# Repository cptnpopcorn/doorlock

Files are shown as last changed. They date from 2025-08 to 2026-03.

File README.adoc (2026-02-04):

# Introduction

This repository is based on code from elmu's electronic doorlock project (see `archive` folder). This project was a real-use, working application to manage access to a house using encrypted DESFire cards from NXP.

What it does is changing the target to a more modular application, where the card verification and door control is separated. The central control mechanism that links those two components can be anything that communicates via MQTT.

A PC-plus-FT232H dongle based programmer application is provided, to manually write user IDs on cards.

## Project Structure

The top folders

common:: shared, generic C++ libraries and applications (CMake-based), and *global configuration*
common-esp32:: shared, esp32-specific libaries ("components")
esp32-cardreader:: esp32 application reading NFC cards and pubslishing extracted user IDs via MQTT

### Common

config:: the one central place to define your secret keys used to encrypt cards and MQTT communication
cardwriter:: desktop CLI application to verify and write cards via a FT232H USB/SPI dongle
external:: some CMake magic to find and integrate your locally installed FTDI dongle libraries
libdesfire:: re-factored NXP PN532 library from elmu (now with runtime hardware abstraction)
libdesfire_tests:: unit tests for rewritten PN532 message parsing abstraction
pn532-ft232h:: PN532 interface implementation via FT232H, working for SPI. Tried I2C but since the FT232H does not support the clock stretching applied by the PN532, it seems to be a dead end..
test-ft232h:: some basic system test to verify / diagnose basic FT232H + PN532 operations

## Card reader application (ESP32)

### Configuration (ESP-IDF menuconfig)

You can set up your specific MQTT subject, encryption etc. under the `MQTT` component settings. For the PN532 specific GPIO pins, they can be changed in the `PN532 GPIO Pins` section.

## Using PN532 from a PC via a FT232H USB Dongle

### Required libraries

* You need to get the ft2xx user space driver (dll or static) as provided by FTDI (https://ftdichip.com/drivers/d2xx-drivers/), including a lib and header file.
* You will also need the MPSSE library, which works on top of the ft2xx library (https://ftdichip.com/software-examples/mpsse-projects/libmpsse-spi-examples/). It includes the sources and you can build it yourself (I had to do that for my Win11 Arm64). I chose to use the static version of that library, see link:src/pn532-ft232h/CMakeLists.txt[CMakeLists.txt] of the `pn532-ft232h` library.

#### Making the FTDI libraries accessible in this project

Since you will have _your_ version of these libraries, depending on your system, and you may want to put them where _you_ find it practical, you will have to tell CMake how to find them, for example using your local user configuration. I think it is rather good practice to not have any user-specific settings with local paths included in this repository.

In Visual Studio Code, you may add something like this to your user settings JSON file:

[,json]
----
"cmake.configureSettings": {
		"CMAKE_TOOLCHAIN_FILE": "C:/Users/hagen/cmake/global_toolchain.cmake"
----

...where you define additional include and library paths in that toolchain file, for example

[,json]
----
set(CMAKE_CXX_FLAGS_INIT "${CMAKE_CXX_FLAGS_INIT} /IC:/Users/hagen/Documents/ft232h")
set(CMAKE_EXE_LINKER_FLAGS_INIT "${CMAKE_EXE_LINKER_FLAGS_INIT} /LIBPATH:C:/Users/hagen/Documents/ft232h")
----

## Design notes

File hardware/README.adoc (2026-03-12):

# Hardware Documentation

This gives some ideas about the hardware used, but without being overly precise. The way I built this first version is probably not optimal for producing it in numbers.
The electronic components to protect from flyback current or DC variations and oscillations are mounted on small pieces of stripboard (with 0.1 inch hole distance),
either 9 x 13 holes or 9 x 9 holes, and screwed to the housing using small M2 inserts, or M3 inserts where possible (also for the case).
                                                                                                                     
## Fire Safety

Instead of common PLA, the cases can be printed using filament of type SPECTRUM PETG FR V0 Natural, 1.75mm. This is self-extinguishing after 10 seconds,
rated UL 94 V-0 and appropriate for permanent installations.

For the cabling between the boxes, and the door strike, LAPP UNITRONIC® LiHH 2 x 0.25 mm² is a good choice. it is certified IEC 60332-1-2, IEC 61034-2
and halogen-free (LSZH), producing less smoke.

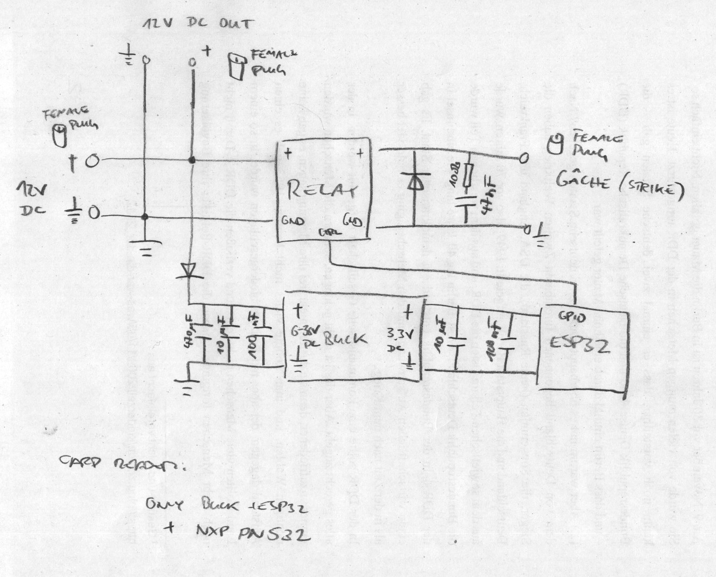
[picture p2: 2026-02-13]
hardware/schema-principle.jpg

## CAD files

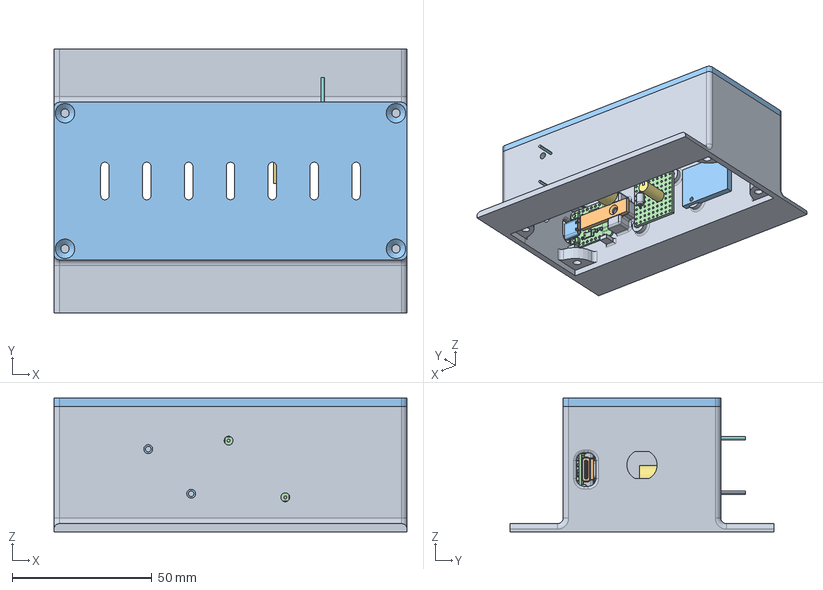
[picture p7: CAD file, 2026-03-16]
hardware/cardreader.FCStd
126.5 x 94.5 x 48.0 mm
case
Beetle ESP32-C6
Beetle ESP32-C007
Beetle ESP32-C008
breadboard_before_buck
1N5408-B
1N5408-B001
1N5408-B002
1N5408-B003
capacitor 100nF cut
DFR1015
breadboard_after_buck
capacitor 100nF after buck
esp fixation
lid

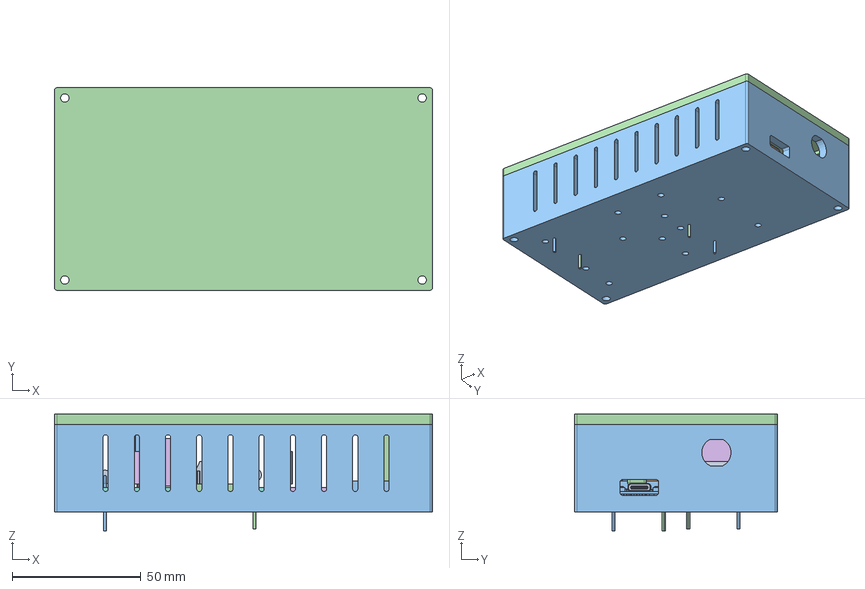
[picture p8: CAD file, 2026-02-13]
hardware/dooropener.FCStd
146.6 x 78.6 x 45.2 mm
Beetle ESP32-C6
Beetle ESP32-C007
Beetle ESP32-C008
DFR1015
Board
RELAY_G5LE-1
SOT23-R
0805-NO
0805-NO001
0805-NO002
0805-NO004
0805-NO005
0805-NO006
0805-NO008
0805-NO009
0805-NO010
SOD-323
CHIPLED_0805_NOOUTLINE
BTN_KMR2_4.6X2.8
BTN_KMR2_4.6X2.009
BTN_KMR2_4.6X2.010
BTN_KMR2_4.6X2.011
BTN_KMR2_4.6X2.012
BTN_KMR2_4.6X2.013
TERMBLOCK_1X3_5.08MM
TERMBLOCK_1X3_5.08MM001
TERMBLOCK_1X3_5.08MM002
TERMBLOCK_1X3_5.08MM003
TERMBLOCK_1X3_5.08MM004
TERMBLOCK_1X3_5.08MM005
TERMBLOCK_1X3_5.08MM006
breadboard_before_buck x 2
1N5408-B x 2
1N5408-B001 x 2
1N5408-B002 x 2
1N5408-B003 x 2
capacitor 100nF cut
breadboard_after_buck
capacitor 100nF after buck
CCR_SB_7.62X10.16_L7.62H10.16T4.07S6.35LL7F0.61
CCR_SB_7.62X10.16_L7.62H10.16T4.07S6.35LL7F0.062
CCR_SB_7.62X10.16_L7.62H10.16T4.07S6.35LL7F0.063
CCR_SB_7.62X10.16_L7.62H10.16T4.07S6.35LL7F0.064
case
lid

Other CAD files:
hardware/dooropener.3mf

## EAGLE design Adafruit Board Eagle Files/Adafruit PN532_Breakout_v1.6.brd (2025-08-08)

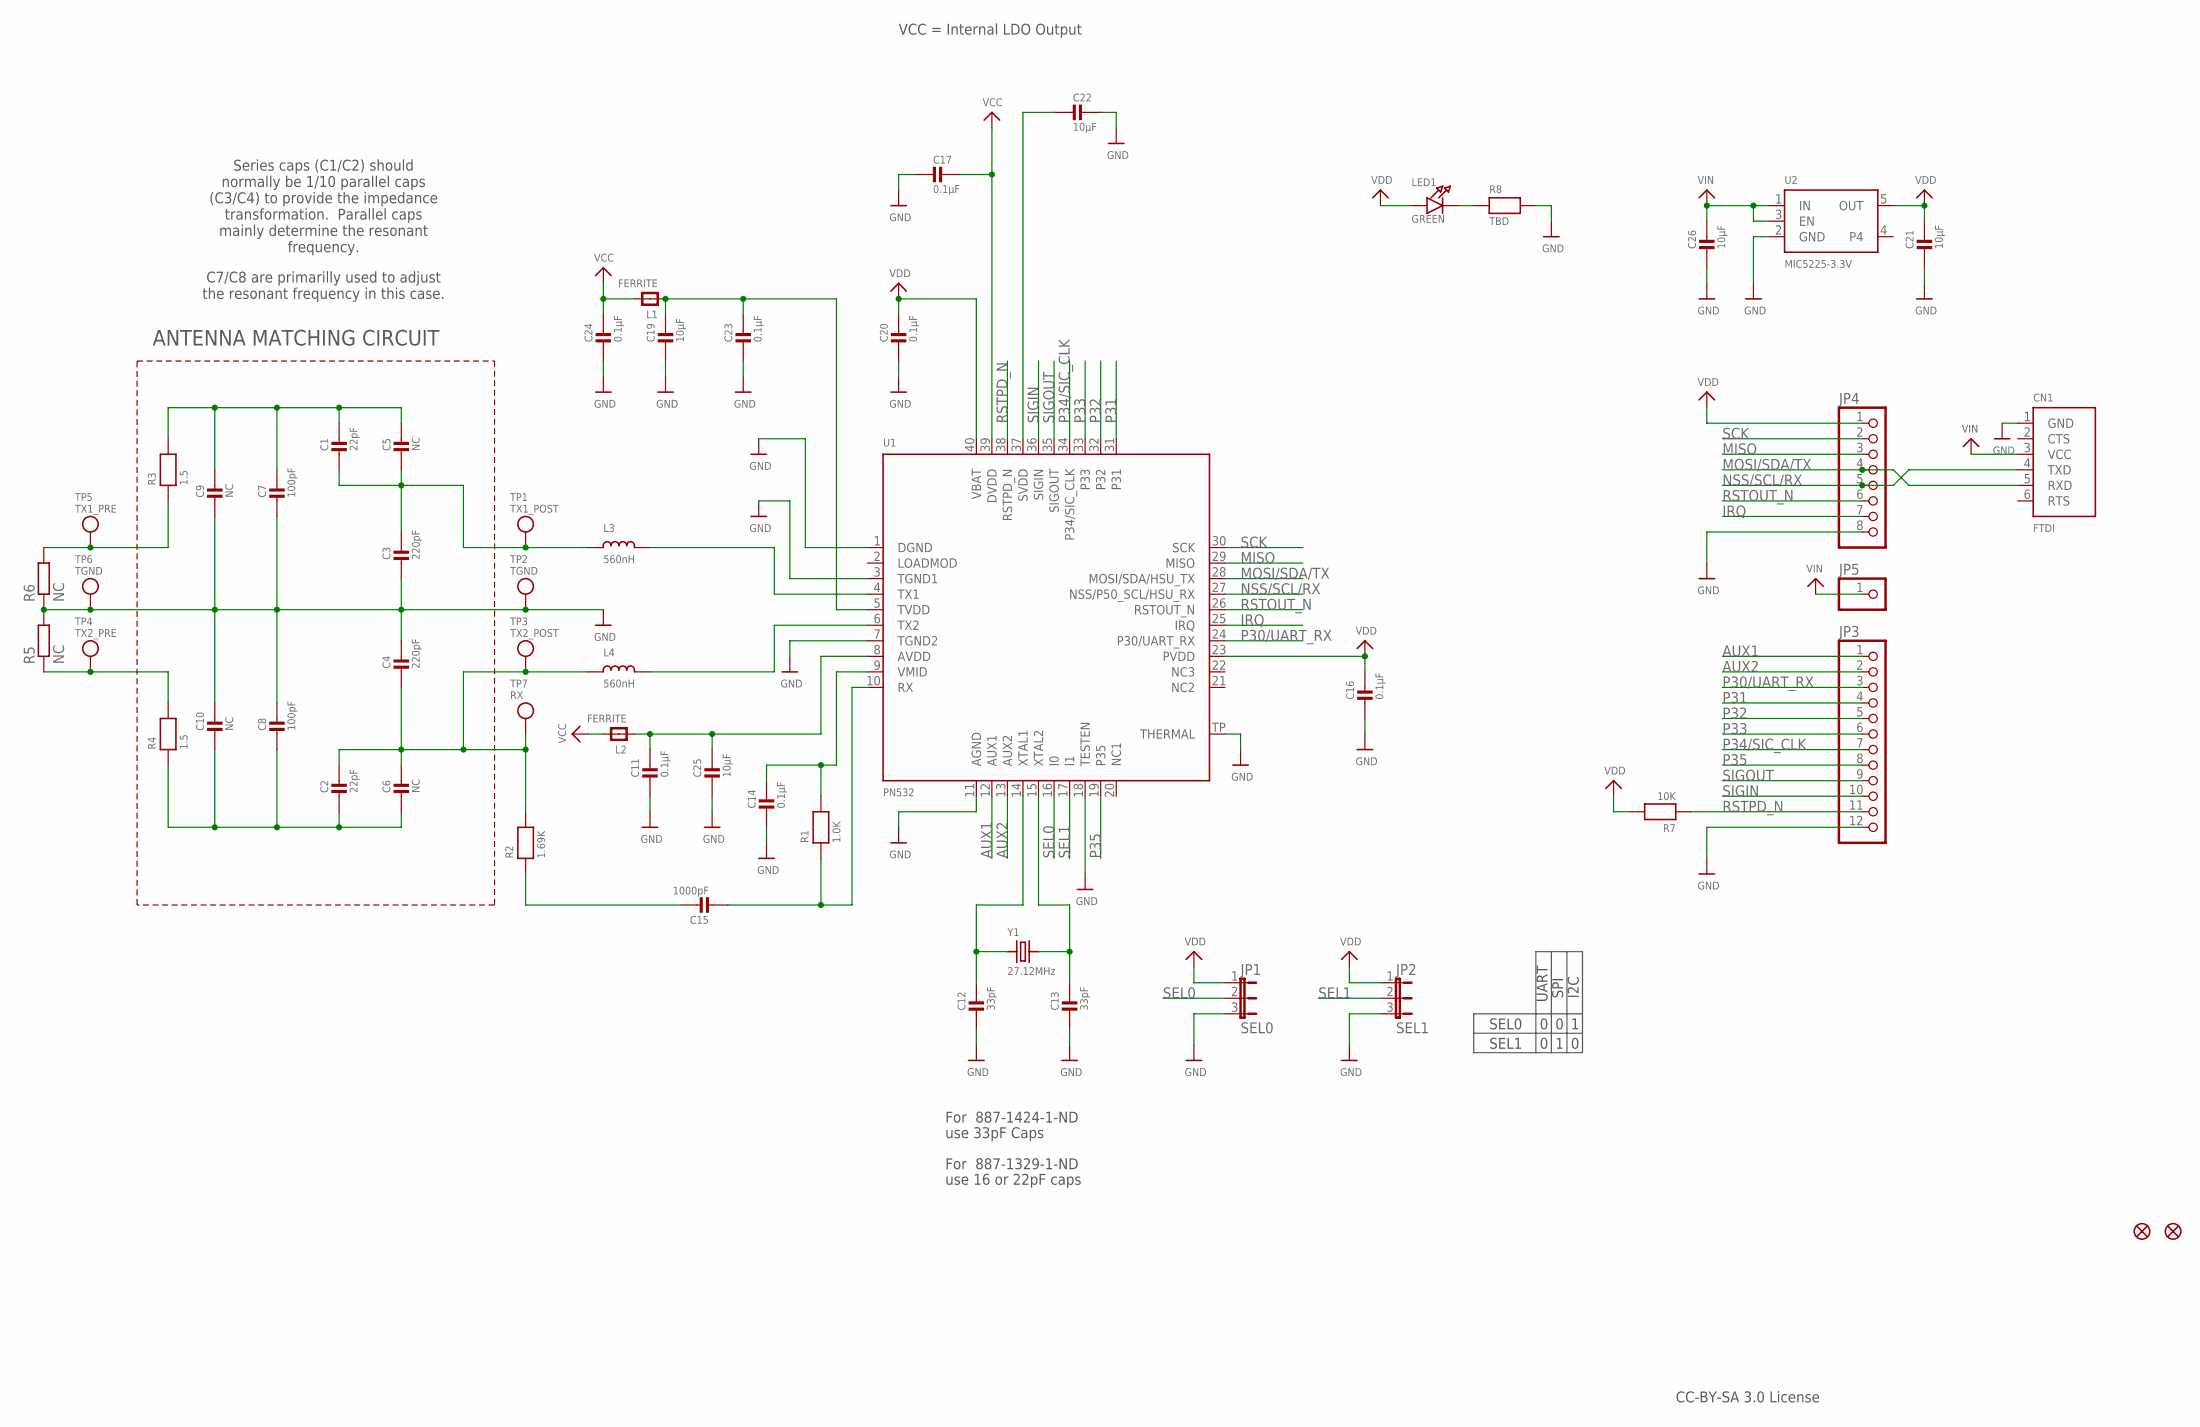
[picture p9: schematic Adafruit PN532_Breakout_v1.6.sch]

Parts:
C1, C2: 22pF; 0805-NO
C3, C4: 220pF; 0805-NO
C5, C6, C9, C10: NC; 0805-NO
C7, C8: 100pF; 0805-NO
C11, C14, C16, C17, C20, C23, C24: 0.1µF; 0805-NO
C12, C13: 33pF; 0805-NO
C15: 1000pF; 0805-NO
C19, C21, C22, C25, C26: 10µF; 0805-NO
CN1: FTDI; 1X06_ROUND
FID1, FID2: FIDUCIAL1X2.5; FIDUCIAL-1X2.5
JP1: SEL0; JUMPER3
JP2: SEL1; JUMPER3
JP3: HEADER-1X12; 1X12_ROUND
JP4: HEADER-1X8ROUND; 1X08_ROUND
JP5: HEADER-1X1ROUND; 1X01_ROUND
L1, L2: FERRITE; 0805
L3, L4: 560nH; 0805
LED1: GREEN; CHIPLED_0805_NOOUTLINE
R1: 1.0K; 0805-NO
R2: 1.69K; 0805-NO
R3, R4: 1.5; 0805-NO
R5, R6: NC; R0201
R7: 10K; 0805-NO
R8: TBD; 0805-NO
TP1: TX1_POST; TESTPOINT_ROUND_1MM
TP2, TP6: TGND; TESTPOINT_ROUND_1MM
TP3: TX2_POST; TESTPOINT_ROUND_1MM
TP4: TX2_PRE; TESTPOINT_ROUND_1MM
TP5: TX1_PRE; TESTPOINT_ROUND_1MM
TP7: RX; TESTPOINT_ROUND_1MM
U1: PN532; HVQFN40-6X6
U2: MIC5225-3.3V; SOT23-5
Y1: 27.12MHz; CRYSTAL_3.2X2.5

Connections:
+5.0V: C26.1, CN1.3 (VCC), JP5.1, U2.1 (IN), U2.3 (EN)
AUX1: JP3.1, U1.12 (AUX1)
AUX2: JP3.2, U1.13 (AUX2)
GND: C3.2, C4.1, C7.2, C8.1, C9.2, C10.1, C11.2, C12.2, C13.2, C14.2, C16.2, C17.2, C19.2, C20.2, C21.2, C22.1, C23.2, C24.2, C25.2, C26.2, CN1.1 (GND), JP1.3, JP2.3, JP3.12, JP4.8, R5.2, R6.1, R8.2, TP2.P$1, TP6.P$1, U1.1 (DGND), U1.3 (TGND1), U1.7 (TGND2), U1.11 (AGND), U1.18 (TESTEN), U1.TP (THERMAL), U2.2 (GND)
IRQ: JP4.7, U1.25 (IRQ)
MISO: JP4.3, U1.29 (MISO)
MOSI/SDA/TX: CN1.5 (RXD), JP4.4, U1.28 (MOSI/SDA/HSU_TX)
unnamed: L3.2, U1.4 (TX1)
unnamed: L4.2, U1.6 (TX2)
unnamed: C1.2, C3.1, C5.2, L3.1, TP1.P$1
unnamed: R3.1, R6.2, TP5.P$1
unnamed: R4.2, R5.1, TP4.P$1
unnamed: LED1.C, R8.1
unnamed: C12.1, U1.14 (XTAL1), Y1.1
unnamed: C13.1, U1.15 (XTAL2), Y1.2
unnamed: C15.1, R2.1
unnamed: C14.1, R1.2, U1.9 (VMID)
unnamed: C15.2, R1.1, U1.10 (RX)
unnamed: C2.1, C4.2, C6.1, L4.1, R2.2, TP3.P$1, TP7.P$1
unnamed: C11.1, C25.1, L2.1, U1.8 (AVDD)
unnamed: C19.1, C23.1, L1.1, U1.5 (TVDD)
unnamed: C22.2, U1.37 (SVDD)
NSS/SCL/RX: CN1.4 (TXD), JP4.5, U1.27 (NSS/P50_SCL/HSU_RX)
P30/UART_RX: JP3.3, U1.24 (P30/UART_RX)
P31: JP3.4, U1.31
P32: JP3.5, U1.32
P33: JP3.6, U1.33
P34/SIC_CLK: JP3.7, U1.34 (P34/SIC_CLK)
P35: JP3.8, U1.19 (P35)
RSTOUT_N: JP4.6, U1.26 (RSTOUT_N)
RSTPD_N: JP3.11, R7.1, U1.38 (RSTPD_N)
SCK: JP4.2, U1.30 (SCK)
SEL0: JP1.2, U1.16 (I0)
SEL1: JP2.2, U1.17 (I1)
SIGIN: JP3.10, U1.36 (SIGIN)
SIGOUT: JP3.9, U1.35 (SIGOUT)
TX1_ANTENNA: C1.1, C5.1, C7.1, C9.1, R3.2
TX2_ANTENNA: C2.2, C6.2, C8.2, C10.2, R4.1
VCC: C17.1, C24.1, L1.2, L2.2, U1.39 (DVDD)
VDD: C16.1, C20.1, C21.1, JP1.1, JP2.1, JP4.1, LED1.A, R7.2, U1.23 (PVDD), U1.40 (VBAT), U2.5 (OUT)

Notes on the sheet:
ANTENNA MATCHING CIRCUIT
SEL0
SEL1
UART
SPI
I2C
CC-BY-SA 3.0 License
For 887-1329-1-ND
use 16 or 22pF caps
For 887-1424-1-ND
use 33pF Caps
VCC = Internal LDO Output
Series caps (C1/C2) should normally be 1/10 parallel caps (C3/C4) to provide the impedance transformation. Parallel caps mainly determine the resonant frequency.
C7/C8 are primarilly used to adjust the resonant frequency in this case.

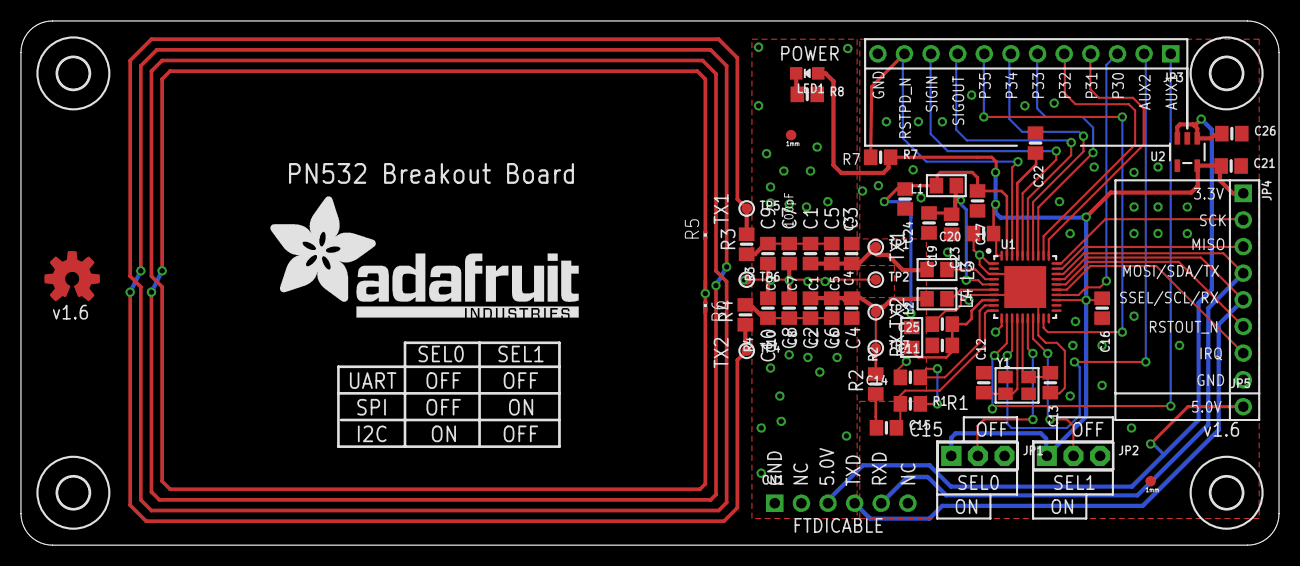
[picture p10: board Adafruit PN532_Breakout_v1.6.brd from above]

Board: 2 copper layers, 120.0 x 50.0 mm, 62 parts (0 on the bottom side), 40 nets.

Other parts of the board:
U$1: ADAFRUIT_TEXT_30MM
U$6, U$36, U$37, U$38: MOUNTINGHOLE_3.0
U$50: OSHWLOGO_TOP_0.2

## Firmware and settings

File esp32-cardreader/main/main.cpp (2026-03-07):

#include <Desfire.h>
#include <Pn532BeetleEsp32C6Spi.h>

#include <soc/spi_reg.h>
#include <driver/usb_serial_jtag.h>
#include <driver/usb_serial_jtag_vfs.h>
#include <esp_event.h>
#include <esp_sleep.h>

#include "mqtt_storage.h"
#include "card_layout.h"
#include "error.h"
#include "interaction_loop.h"
#include "mqtt_config.h"
#include "nvs_access.h"
#include "mqtt_wrapper.h"
#include "secrets.h"
#include "setup.h"
#include "wifi_connection.h"
#include "wifi_station.h"

#include <array>
#include <atomic>
#include <chrono>
#include <exception>
#include <iostream>
#include <system_error>
#include <thread>
#include <utility>

using namespace std;
using namespace std::chrono;

#ifdef CONFIG_MQTT_USE_TLS
span<const uint8_t> get_ca_crt()
{
    return secrets::MQTT_CA_CERT;
}
#else
span<const uint8_t> get_ca_crt()
{
    return {};
}
#endif

#ifdef CONFIG_MQTT_TLS_CLIENT_AUTH
extern "C"
{
    span<const uint8_t> get_client_crt()
    {
        return secrets::MQTT_CLIENT_CERT;
    }
    span<const uint8_t> get_client_key()
    {
        return secrets::MQTT_CLIENT_KEY;
    }
}
#else
span<const uint8_t> get_client_crt()
{
    return {};
}
span<const uint8_t> get_client_key()
{
    return {};
}
#endif

static inline void set_key(AES& aes, const array<uint8_t, 16>& key, uint8_t version)
{
	aes.SetKeyData(key.data(), key.size(), version);
}

extern "C" void app_main(void)
{
	try
	{
		cout << "setting up PN532 SPI communication.." << endl;
		Pn532BeetleEsp32C6Spi pn_spi{500ms};

		check(esp_event_loop_create_default());

		nvs_access nvs{"cardreader"};
		wifi_station wifi{nvs};

		const mqtt_config mqtt_config{
			CONFIG_MQTT_BROKER_HOSTNAME,
			get_ca_crt(),
			get_client_crt(),
			get_client_key()};
	
		if (usb_serial_jtag_is_connected())
		{
			this_thread::sleep_for(10s); // allows to quickly open a terminal, after plugging in USB
			cout << "USB console connected, entering interactive mode.." << endl;

			setvbuf(stdin, nullptr, _IONBF, 0);
			usb_serial_jtag_driver_config_t usb_serial_jtag_config{.tx_buffer_size = 1024, .rx_buffer_size = 1024};
			check(usb_serial_jtag_driver_install(&usb_serial_jtag_config), "JTAG driver install");
			usb_serial_jtag_vfs_use_driver();

			interaction_loop loop{};
			setup s{loop.stop(), wifi, mqtt_config, nvs, pn_spi};
			loop.set(s);
			loop.start();
		}

		cout << "connecting WiFi.." << endl;
		wifi_connection connection{wifi};
		connection.start();
		if (!connection.wait_is_up(pdMS_TO_TICKS(20'000))) throw runtime_error{"WiFi connection timeout"};

		cout << "connecting to MQTT broker " << mqtt_config.broker_host << ".." << endl;
		mqtt_wrapper publisher{mqtt_config.broker_host,  mqtt_storage::read_topic(nvs).card_reader_str(), mqtt_config.ca_cert, mqtt_config.client_cert, mqtt_config.client_key};
		if (!publisher.wait_is_connected(pdMS_TO_TICKS(5'000))) throw runtime_error{"MQTT connection timeout"};

		cout << "setting up NFC chip.." << endl;

		AES piccMasterKey;
		AES doorlockMasterKey;
		AES doorlockWriteKey;
		AES doorlockReadKey;

		set_key(piccMasterKey, secrets::CARD_PICC_MASTER_AES_KEY, to_underlying(KeyVersionPicc::Master));
		set_key(doorlockMasterKey, secrets::CARD_DOORLOCK_MASTER_AES_KEY, to_underlying(KeyVersionDoorlock::Master));
		set_key(doorlockWriteKey, secrets::CARD_DOORLOCK_WRITE_AES_KEY, to_underlying(KeyVersionDoorlock::Write));
		set_key(doorlockReadKey, secrets::CARD_DOORLOCK_READ_AES_KEY, to_underlying(KeyNumberDoorlock::Read));

		Desfire des{pn_spi};
		des.SetDebugLevel(0);
		des.begin();

		if (!des.SetPassiveActivationRetries()) throw runtime_error{"error configuring card retries"};
		if (!des.SamConfig())  runtime_error{"could not configure card secure access"};

		cout << "waiting for card.." << endl;

		for (;;this_thread::sleep_for(500ms))
		{
			(cout << '.').flush();
			
			array<uint8_t, 8> uid;
			uint8_t uid_length {0};
			eCardType cardType {};

			if (!des.ReadPassiveTargetID(uid.data(), &uid_length, &cardType) || uid_length == 0) continue;

			if (!des.SelectApplication(to_underlying(ApplicationId::Picc)))
			{
				cout << "not a \"DESFire EV\" card" << endl;
				continue;
			}
			
			if (!des.Authenticate(to_underlying(KeyNumberPicc::Master), &piccMasterKey))
			{
				cout << "card protected with unknown master key" << endl;
				continue;
			}

			if (!des.SelectApplication(to_underlying(ApplicationId::Doorlock)))
			{
				cout << "no data present" << endl;
				continue;
			}

			if (!des.Authenticate(to_underlying(KeyNumberDoorlock::Read), &doorlockReadKey))
			{
				cout << "application protected with unknown key" << endl;
				continue;
			}

			array<uint8_t, static_cast<size_t>(FileSize::PublicuserId)> user_id;
			if (!des.ReadFileData(to_underlying(FileId::PublicUserId), 0, user_id.size(), user_id.data()))
			{
				cout << "could not read user ID" << endl;
				continue;
			}

			if (!publisher.publish(user_id)) throw runtime_error{"could not publish ID via MQTT"};
		}
	}
	catch(const exception &e)
	{
		cerr << e.what() << endl;
	}

	cout << "wait and reboot" << endl;
	esp_deep_sleep(4'000'000);
}

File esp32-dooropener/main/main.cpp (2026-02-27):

#include <driver/usb_serial_jtag.h>
#include <driver/usb_serial_jtag_vfs.h>
#include <esp_sleep.h>

#include "error.h"
#include "interaction_loop.h"
#include "mqtt_config.h"
#include "mqtt_storage.h"
#include "mqtt_wrapper.h"
#include "nvs_access.h"
#include "secrets.h"
#include "wifi_connection.h"
#include "wifi_station.h"
#include "const_stream.h"
#include "open_message_builder.h"
#include "setup.h"

#include "rapidjson/reader.h"
#include "rapidjson/error/en.h"

#include <chrono>
#include <exception>
#include <iostream>
#include <string>
#include <system_error>
#include <thread>
#include <utility>

using namespace std;

#ifdef CONFIG_MQTT_USE_TLS
span<const uint8_t> get_ca_crt()
{
    return secrets::MQTT_CA_CERT;
}
#else
span<const uint8_t> get_ca_crt()
{
    return {};
}
#endif

#ifdef CONFIG_MQTT_TLS_CLIENT_AUTH
extern "C"
{
    span<const uint8_t> get_client_crt()
    {
        return secrets::MQTT_CLIENT_CERT;
    }
    span<const uint8_t> get_client_key()
    {
        return secrets::MQTT_CLIENT_KEY;
    }
}
#else
span<const uint8_t> get_client_crt()
{
    return {};
}
span<const uint8_t> get_client_key()
{
    return {};
}
#endif

extern "C" void app_main(void)
{
	try
	{
		check(esp_event_loop_create_default());

		nvs_access nvs{"dooropener"};
		wifi_station wifi{nvs};

		const mqtt_config mqtt_config{
			CONFIG_MQTT_BROKER_HOSTNAME,
			get_ca_crt(),
			get_client_crt(),
			get_client_key()};

		if (usb_serial_jtag_is_connected())
		{
			this_thread::sleep_for(10s); // allows to quickly open a terminal, after plugging in USB
			cout << "USB console connected, entering interactive mode.." << endl;

			setvbuf(stdin, nullptr, _IONBF, 0);
			usb_serial_jtag_driver_config_t usb_serial_jtag_config{.tx_buffer_size = 1024, .rx_buffer_size = 1024};
			check(usb_serial_jtag_driver_install(&usb_serial_jtag_config), "JTAG driver install");
			usb_serial_jtag_vfs_use_driver();

			interaction_loop loop{};
			setup s{loop.stop(), wifi, mqtt_config, nvs, static_cast<gpio_num_t>(CONFIG_RELAY_GPIO_PIN)};
			loop.set(s);
			loop.start();
		}

		// GPIO relay operation
		cout << "starting relay controller.." << endl;
		RelayController relay {pdMS_TO_TICKS(2'000), static_cast<gpio_num_t>(CONFIG_RELAY_GPIO_PIN)};

		cout << "connecting WiFi.." << endl;
		wifi_connection connection{wifi};
		connection.start();
		if (!connection.wait_is_up(pdMS_TO_TICKS(20'000))) throw runtime_error{"WiFi connection timeout"};

		cout << "connecting to MQTT broker " << mqtt_config.broker_host << ".." << endl;
		const auto topic = mqtt_storage::read_topic(nvs);
		mqtt_wrapper listener{mqtt_config.broker_host, topic.door_opener_str(), mqtt_config.ca_cert, mqtt_config.client_cert, mqtt_config.client_key};
		if (!listener.wait_is_connected(pdMS_TO_TICKS(5'000))) throw runtime_error{"MQTT connection timeout"};

		cout << "subscribing to topic " << topic.door_opener_str() << endl;
		if (!listener.subscribe([&relay](const auto& data)
		{
			OpenMessageBuilder message{};
			ConstStream stream{data};
			try
			{
				rapidjson::Reader{}.Parse(stream, message);
				if (message.is_valid())
				{
					cout << (message.get_open() ? "open" : "do not open") << " for " << message.get_user() << endl;
					relay.Close();
				}
				else
				{
					cout << "invalid message format" << endl;
				}
			}
			catch (const exception& e)
			{
				cout << "malformatted open message" << endl << e.what() << endl;
			}
		}))
		{
			throw runtime_error {"MQTT subscription failed"};
		}

		cout << "waiting for messages.." << endl;
		listener.wait_is_disconnected(portMAX_DELAY);
		cout << "MQTT disconnected" << endl;
	}
	catch (const exception &e)
	{
		cerr << e.what() << endl;
	}

	cout << "wait and reboot" << endl;
	esp_deep_sleep(4'000'000);
}

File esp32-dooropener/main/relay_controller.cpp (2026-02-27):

#include "relay_controller.h"
#include "bounce.h"

#include <freertos/FreeRTOS.h>
#include <freertos/task.h>
#include <system_error>
#include <iostream>

using namespace std;

RelayController::RelayController(TickType_t duration, gpio_num_t pin) : events{xEventGroupCreate()}, duration{duration}, pin{pin}
{
	if (xTaskCreate(BOUNCE(RelayController, WaitForClose), "relay controller", 4096, this, tskIDLE_PRIORITY, nullptr) != pdPASS)
	{
		throw runtime_error { "could not create relay controller task" };
	}

	gpio_config_t pin_conf {};
	pin_conf.pin_bit_mask = 1ULL << pin;
	pin_conf.mode = GPIO_MODE_OUTPUT;
	pin_conf.pull_up_en = GPIO_PULLUP_DISABLE;
	pin_conf.pull_down_en = GPIO_PULLDOWN_DISABLE;
	pin_conf.intr_type = GPIO_INTR_DISABLE;

	if (gpio_config(&pin_conf) != ESP_OK) throw runtime_error{"bad GPIO pin (OPEN)"};

	gpio_set_level(pin, 0);
}

static constexpr uint32_t RELAY_CONTROLLER_EVENT_CLOSE { 1 << 0 };
static constexpr uint32_t RELAY_CONTROLLER_EVENT_STOP { 1 << 1 };
static constexpr uint32_t RELAY_CONTROLLER_EVENT_STOPPED { 1 << 2 };

void RelayController::Close()
{
	xEventGroupSetBits(events, RELAY_CONTROLLER_EVENT_CLOSE);
}

RelayController::~RelayController()
{
	xEventGroupSetBits(events, RELAY_CONTROLLER_EVENT_STOP);
	xEventGroupWaitBits(events, RELAY_CONTROLLER_EVENT_STOPPED, pdTRUE, pdFALSE, portMAX_DELAY);
}

void RelayController::WaitForClose()
{
	for (;;)
	{
		const auto bits = xEventGroupWaitBits(
			events,
			RELAY_CONTROLLER_EVENT_CLOSE | RELAY_CONTROLLER_EVENT_STOP,
			pdTRUE,
			pdFALSE,
			portMAX_DELAY);

		if ((bits & RELAY_CONTROLLER_EVENT_STOP) != 0)
		{
			xEventGroupSetBits(events, RELAY_CONTROLLER_EVENT_STOPPED);
			vTaskDelete(nullptr);
			return;
		}

		if ((bits & RELAY_CONTROLLER_EVENT_CLOSE) != 0)
		{
			gpio_set_level(pin, 1);
			xEventGroupWaitBits(events, RELAY_CONTROLLER_EVENT_STOP, pdFALSE, pdFALSE, duration);
			gpio_set_level(pin, 0);
		}
	}
}

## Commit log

2025-08-08 Copy of the project from the CodeProject website
    URL: https://www.codeproject.com/Articles/1096861/DIY-electronic-RFID-Door-Lock-with-Battery-Backup
    [Adafruit PN532_Breakout_v1.6.brd, Adafruit PN532_Breakout_v1.6.sch, NXP AN166510 Amplifier antenna matching calculation.xls]
2025-09-07 completely abstract reset and command transport into simple interface
    [PN532.cpp]
2025-11-09 add FT232H based cardwriter CLI app
    fix PN532 lib to not skip lower layer comm protocol bytes, since they are not there anymore
    [Ft232hI2C.cpp, Ft232hSpi.cpp]
2025-11-23 avoid throwing during parsing, just return false
    [PN532.cpp]
2025-11-24 finalize working CLI card reader
    using FT232H+SPI, for now
    ideally, I'll get the FT4222h working to use the DFRobot PN532 via I2C, alternatively
2025-11-26 move original files to archive folder, set up common workspace exlusively
    [Adafruit PN532_Breakout_v1.6.brd, Adafruit PN532_Breakout_v1.6.sch, NXP AN166510 Amplifier antenna matching calculation.xls]
2025-11-26 add ESP32-C6 card reader application stub
2025-11-28 first shot at an ESP32-SPI implementation
    fixed dependency issues with the component wrapper for the external libdesfire
    [PN532OverFT232HI2C.cpp, PN532OverFT232HSPI.cpp, main.cpp]
2025-12-08 first working ESP32C6 SPI comm
2025-12-13 add MQTT config options to ESP32 SDK car reader app
2025-12-14 make ESP32 GPIO pins configurable in menu config
2026-01-06 fix mqtt secrets usage and improve generation format
    [main.cpp]
2026-02-04 move esp32 components outside reader app, for reuse
2026-02-04 start case design for opener component
    [dooropener.FCStd]
2026-02-04 reorganize esp-idf configuration sections, some more documentation
    better keep MQTT setup and PN532 pin layout separate, even though it's less obvious to find
    will be mentioned in readme
2026-02-11 work on opener case
    [dooropener.3mf, dooropener.FCStd]
2026-02-13 improve case and add electrical schema~
    [dooropener.3mf, dooropener.FCStd]
2026-02-13 shrink dc connector holes, in practice they don't need to be much bigger than the connector
    [dooropener.3mf, dooropener.FCStd]
2026-02-21 adjust case model
    [cardreader.FCStd]
2026-02-23 fix some project setups, continue on opener app stub
    [main.cpp]
2026-02-25 swap future with native FreeRTOS notification - guarantees event loop handling while waiting
    [main.cpp]
2026-02-25 fixup thread synchronization
2026-02-27 add relay operation
2026-03-03 work on reader case model
    [cardreader.FCStd]
2026-03-07 update cardreader case model
    [cardreader.FCStd]
2026-03-09 add precise but FreeRTOS task friendly hw timer
2026-03-09 use hw timer for ESP32 SPI waiting
2026-03-09 disable WiFi power saving
    either we use WiFi while plugged in or only briefly, connecting and disconnecting quickly anyway
2026-03-09 update card reader model
    [dooropener.3mf]
2026-03-16 adjust some details of cardreader model
    make vent slits smaller, add rim for lid fixation, better esp32 placement
    [cardreader.FCStd, dooropener.3mf]
